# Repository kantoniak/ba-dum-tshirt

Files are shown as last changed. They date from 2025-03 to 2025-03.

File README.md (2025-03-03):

# Ba-Dum-Tshirt

A T-shirt embroidered with conductive thread that plays sounds when the pads are touched.

<p align="center">
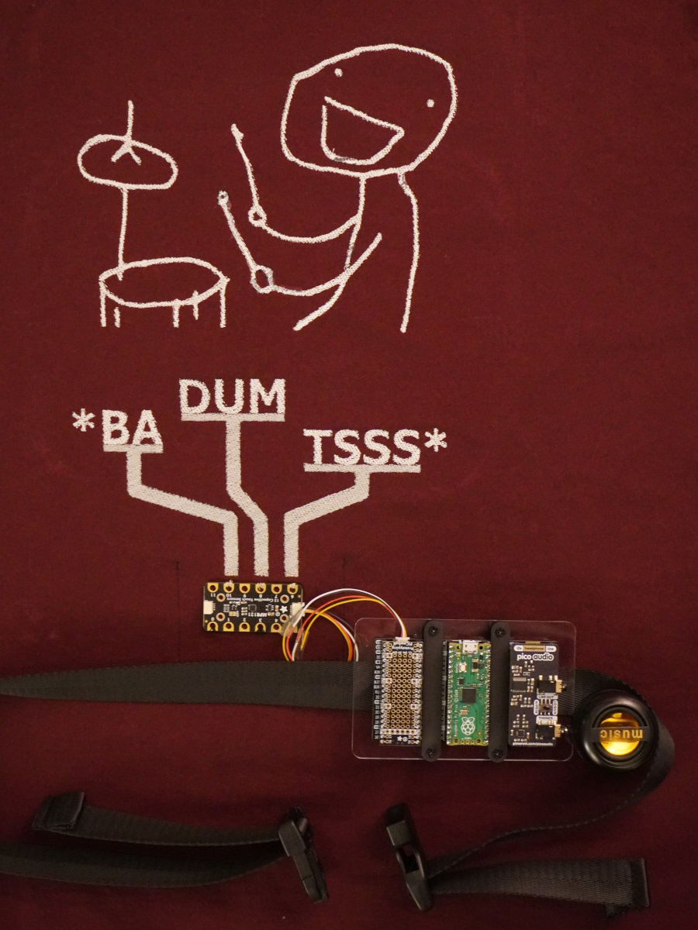
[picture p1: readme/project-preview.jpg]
  
</p>

## Embroidery

<p align="center">
  
</p>

Choose your preferred garment and embroider it using a compatible machine.
The design was created in Inkscape for a 200x280 mm hoop and can be digitized with [Ink/Stich](https://inkstitch.org/).
To fit the working area of the Janome MC400E, I had to split the design into two 200x200 mm sections.

Embroider the red areas with conductive thread and use regular embroidery thread for the black areas.
After assembling hardware, sew the touch-sensing board to the garment.
Use thick conductive thread to connect the conductive areas to the corresponding pads on the board.

## Hardware

### Required hardware

- [Raspberry Pi Pico](https://www.raspberrypi.com/products/raspberry-pi-pico/)
- Pimoroni's [Pico Audio Pack](https://pimoroni.com/audiopack)
- Any MPR121 touch sensor board, such as the [Adafruit #4830](https://www.adafruit.com/product/4830)
- A speaker with a mini-jack input

### Optional add-ons

For convenience and minimal soldering, the following were also used:
- Pimoroni's [Pico Omnibus](https://shop.pimoroni.com/products/pico-omnibus)
- [Adafruit PiCowbell Proto](https://www.adafruit.com/product/5200)
- A JST SH 4-pin cable

## Firmware

1. Install [CircuitPython](https://circuitpython.org/board/raspberry_pi_pico/) on your Pico.
2. Copy [CircuitPython 9.x libraries](https://github.com/adafruit/Adafruit_CircuitPython_Bundle/releases/tag/20250228) to your pico. You only need a subset of files if you want to save on some space. Copy to `lib/` at least the following:
    * `adafruit_bus_device`
    * `adafruit_debouncer.mpy`
    * `adafruit_mpr121.mpy`
    * `adafruit_ticks.mpy`

## Enclosure

<p align="center">
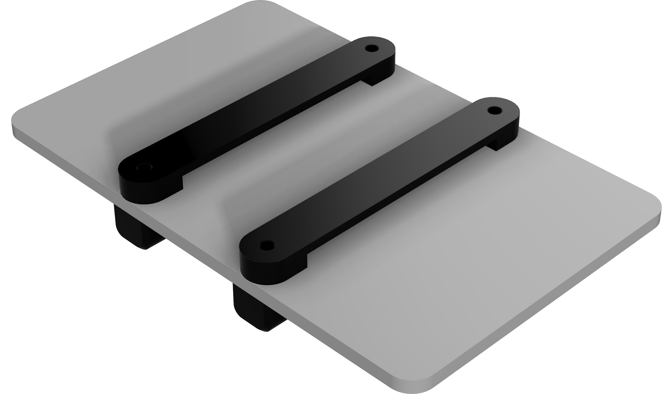
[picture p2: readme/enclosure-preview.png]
  
</p>

This is currently more of a backplate and is entirely optional.
Cut the backplate (`laser-outline-rev1.pdf`) from 3 mm acrylic using a laser cutter.
Print two copies each of `holder-top.3mf` and `holder-bottom.3mf` using a 3D printer.
Sandwich the PCB under the clamps and secure it with four M3x13 mm screws.
Thread 1-inch webbing through the loops in the bottom parts and attach a side-release buckle to the free ends.
You can finish the ends of the webbing on a sewing machine.

## Acknowledgements

* I couldn't find the author of [the meme](https://knowyourmeme.com/memes/rimshot-ba-dum-tss)'s picture.
* Sounds adapted from [*Ba-Dum-Tss* recording](https://freesound.org/people/VeinAdams/sounds/713649/) by [VeinAdams](https://freesound.org/people/VeinAdams/).

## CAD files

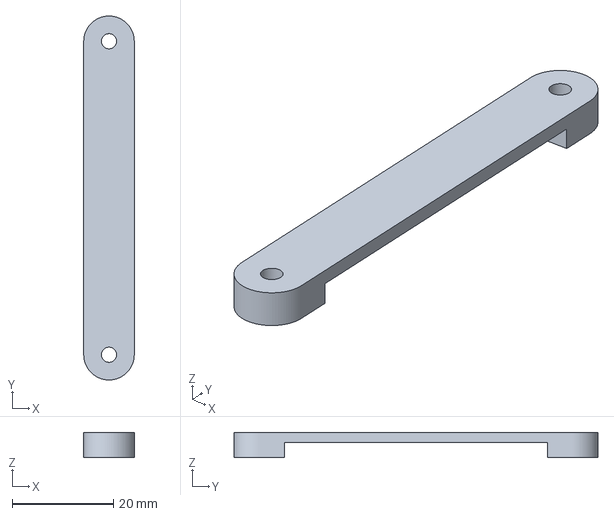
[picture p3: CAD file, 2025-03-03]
enclosure/holder-top-rev1.3mf
10.0 x 72.0 x 5.00 mm

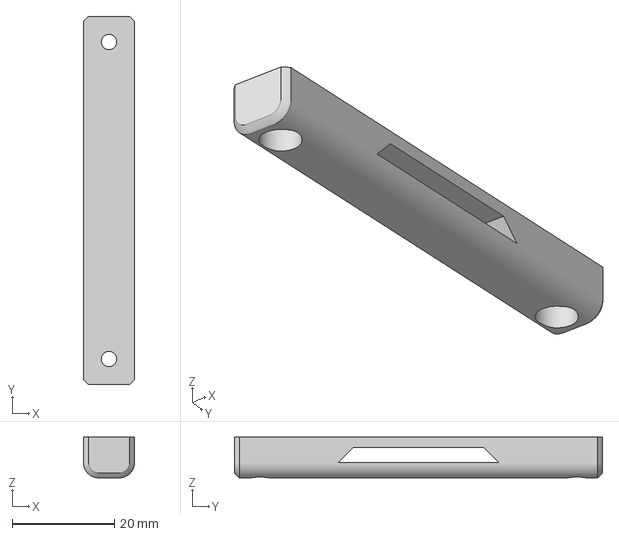
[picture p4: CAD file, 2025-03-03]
enclosure/holder-bottom-rev3.3mf
10.0 x 72.0 x 8.00 mm

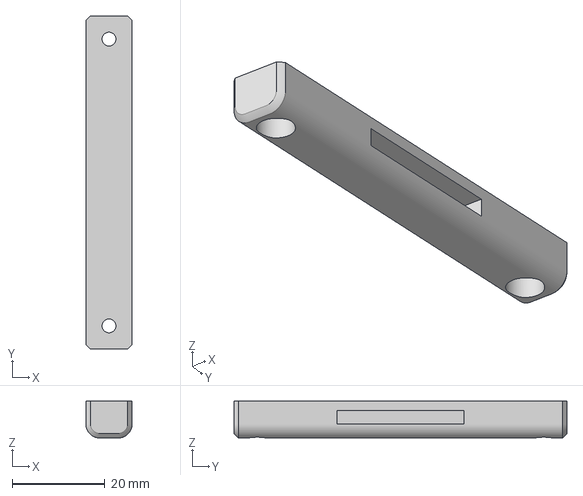
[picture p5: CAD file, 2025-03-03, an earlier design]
enclosure/holder-bottom-rev1.3mf
10.0 x 72.0 x 8.00 mm

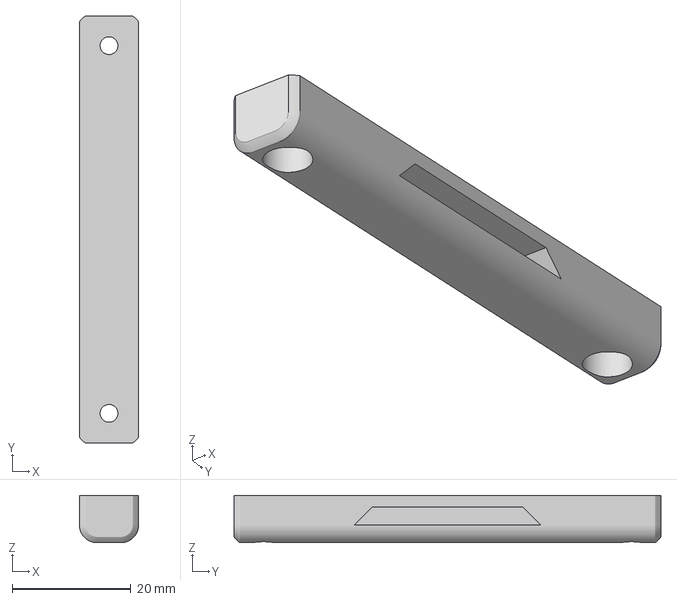
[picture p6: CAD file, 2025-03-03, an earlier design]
enclosure/holder-bottom-rev2.3mf
10.0 x 72.0 x 8.00 mm

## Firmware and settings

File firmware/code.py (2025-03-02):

"""
Sound player main app. Plays "Ba-Dum-Tss" as separate sounds.
"""
import board
from adafruit_debouncer import Button
from adafruit_mpr121 import MPR121, MPR121_Channel
from audiobusio import I2SOut
from audiocore import WaveFile
from audiomixer import Mixer
from busio import I2C


# Set up buttons
i2c = I2C(board.GP5, board.GP4)
touchpad = MPR121(i2c)
buttons = []

for pad_num in [10, 8, 6]:
  # Lower sensitivity of the touch buttons
  channel = MPR121_Channel(touchpad, pad_num)
  channel.threshold = 7
  channel.release_threshold = 3

for pad in touchpad:
  buttons.append(Button(pad, value_when_pressed=True))


# Set up audio
audio = I2SOut(board.GP10, board.GP11, board.GP9)
mixer = Mixer(voice_count=3, sample_rate=16000, channel_count=1, bits_per_sample=16, samples_signed=True)
audio.play(mixer)

sound_ba = WaveFile("sounds/ba.wav")
sound_dum = WaveFile("sounds/dum.wav")
sound_tss = WaveFile("sounds/tss.wav")

def play_sound_on_voice(voice: int, sound: WaveFile):
  if mixer.voice[voice].playing:
    return
  mixer.voice[voice].play(sound)


# Wait for pad presses
while True:
  for i in range(12):
    buttons[i].update()
    if buttons[i].pressed:
      print(f"Pad #{i} touched!")
      if i == 10:
        play_sound_on_voice(0, sound_ba)
      if i == 8:
        play_sound_on_voice(1, sound_dum)
      if i == 6:
        play_sound_on_voice(2, sound_tss)

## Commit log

2025-02-27 Play WAV sounds through `audiomixer`
    * Switch from MicroPython to CircuitPython
    * Change tone generation to WAV files
    * User `audiomixer` to combine sounds
2025-03-03 Add enclosure
    [holder-bottom-rev1.3mf, holder-bottom-rev2.3mf, holder-bottom-rev3.3mf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]
